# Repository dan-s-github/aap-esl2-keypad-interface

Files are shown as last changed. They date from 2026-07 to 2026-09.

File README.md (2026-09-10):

# AAP ESL-2 Keypad Interface

ESPHome firmware and a custom PCB to talk to the keypad bus of an [Arrowhead Alarm Products](https://www.aap.co.nz) EliteControl **ESL-2** panel, so it can be integrated into Home Assistant through the [`crow_alarm_panel`](https://github.com/dan-s-github/esphome-components) external component. It builds on my `crow_alarm_panel` implementation, which handles the AAP keypad bus protocol.

| PCB | PCB with Atom Lite | Side View |
| --- | --- | --- |
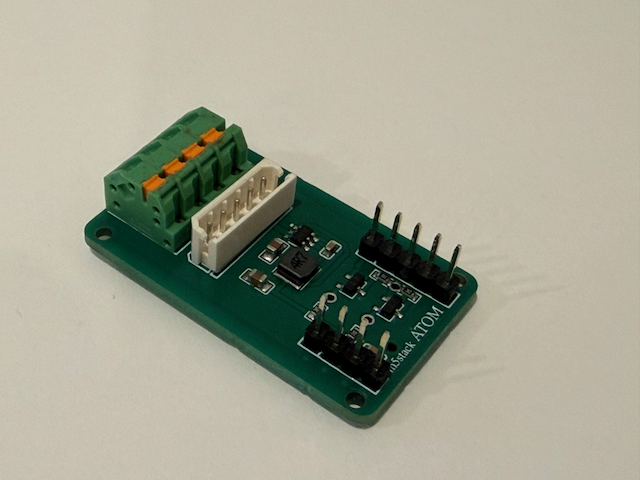
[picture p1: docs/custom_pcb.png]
Custom PCB
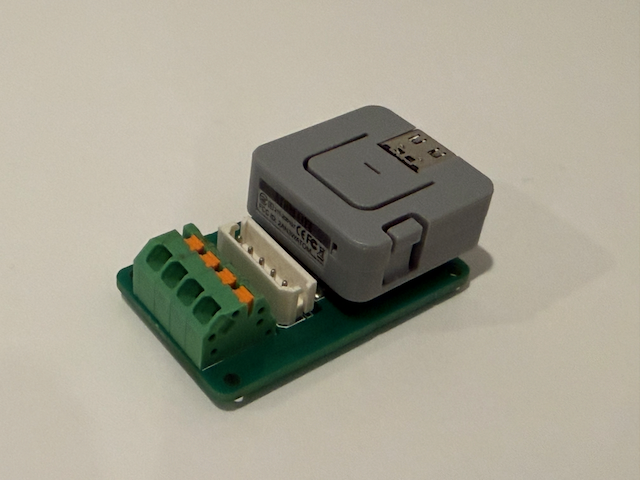
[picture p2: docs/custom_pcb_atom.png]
Custom PCB with Atom Lite
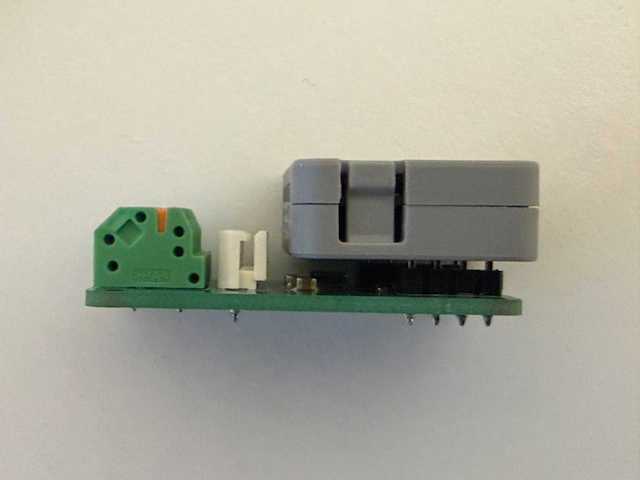
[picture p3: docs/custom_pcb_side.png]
Custom PCB on the side
|  |  |  |

The ESL-2 keypad bus is a shared clock/data bus that regular AAP keypads talk to. This project adds an [M5Stack Atom Lite](https://docs.m5stack.com/en/core/Atom%20Lite) or [M5Stack AtomS3 Lite](https://docs.m5stack.com/en/core/AtomS3%20Lite) to the bus as an extra keypad, so it can read zone/arm state and issue arm/disarm/output commands over Wi-Fi, without touching the panel's existing keypads.

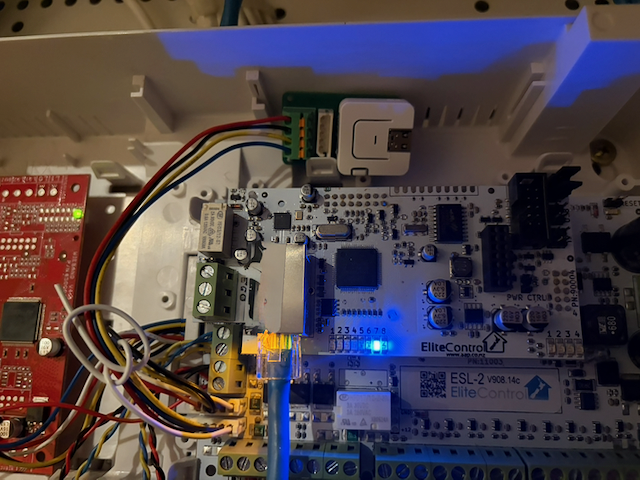
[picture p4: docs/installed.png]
Installed
  

## How it works

The panel supplies +12V to power the bus, but the clock/data lines themselves run at 5V, while the AtomS3 Lite module's GPIOs are 3.3V. The custom PCB sits between the two:

- An [`AP63205WU-7`](https://www.diodes.com/part/view/AP63205) buck converter steps the bus's +12V supply down to +5V, used as the CLK/DATA logic-high reference and to power the module.
- Two `BSS138` MOSFETs form bidirectional logic-level shifters for the CLK and DATA lines, translating between the bus side (5V) and the module side (3.3V).
- The PCB's pin header/Grove-compatible footprint matches the Atom Lite, so it plugs straight onto the PCB with no jumper wires — only the bus connection (panel to PCB) needs wiring, covered in [Connection diagram](#connection-diagram).

The header footprint matches the M5Stack ATOM family in general, so the original [M5Stack Atom Lite](https://docs.m5stack.com/en/core/ATOM%20Lite) (ESP32) works as a drop-in alternative to the AtomS3 Lite — it needs the plain `esp32` variant instead of `esp32s3`, plus different `clock_pin`/`data_pin` values in the YAML, since the Atom Lite exposes a different set of GPIOs than the AtomS3 Lite.

There is no dedicated address pin/DIP switch — the keypad address used on the bus is set entirely in the ESPHome YAML (see [Configuration](#configuration) below).

## Custom PCB

All manufacturing files (schematic, gerbers, BOM, pick-and-place, and the EasyEDA source project) are in [`docs/pcb`](docs/pcb/), ready to order from a board house such as [JLCPCB](https://jlcpcb.com/).

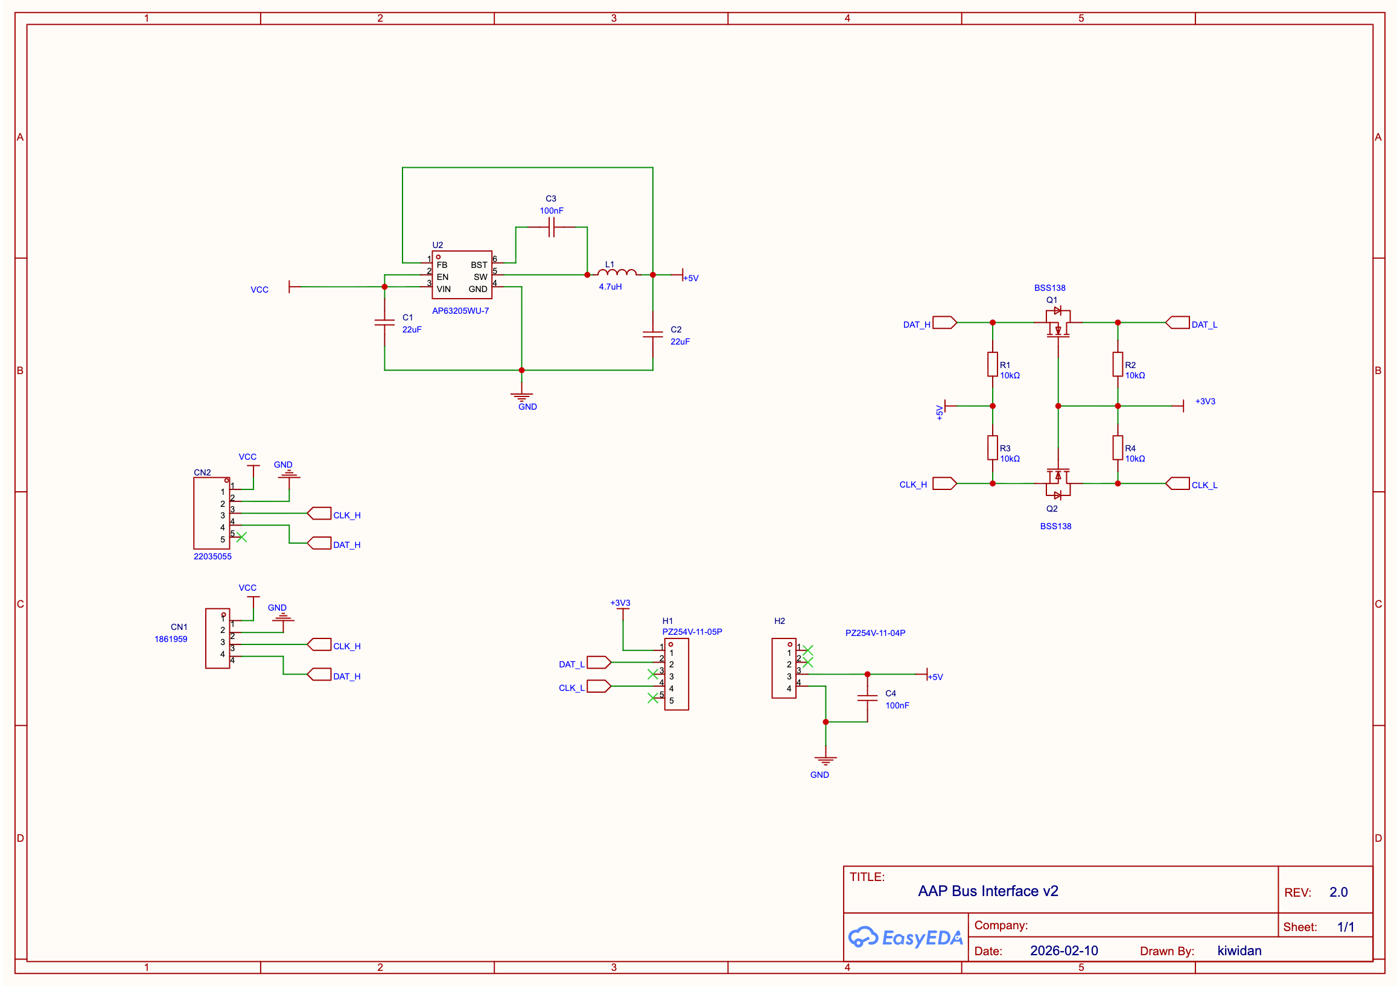
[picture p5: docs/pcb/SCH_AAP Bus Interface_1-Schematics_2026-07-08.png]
Schematics
  

- [Schematics PDF](docs/pcb/SCH_AAP%20Bus%20Interface_2026-07-08.pdf)
- [EasyEDA project](docs/pcb/ProPrj_AAP%20Bus%20Interface%20v2_2026-07-08.epro2) / [EasyEDA doc](docs/pcb/ProDoc_AAP%20Bus%20Interface_2026-07-08.epro2)

Files required to order boards from JLCPCB:

- [Gerber files](docs/pcb/Gerber_PCB_AAP_Bus_Interface_2026-07-08.zip)
- [Bill of Materials](docs/pcb/BOM_AAP%20Bus%20Interface_PCB_AAP%20Bus%20Interface_2026-07-08.csv)
- [Pick and Place](docs/pcb/PickAndPlace_PCB_AAP%20Bus%20Interface_2026_07_08.csv)

### Board layout

The top side mounts the AtomS3 Lite and carries the buck converter and level shifters. The bottom side breaks out the bus connection, silkscreened with the wire colors used on the ESL-2 keypad harness:

| Silkscreen | Signal | Wire color |
|---|---|---|
| +12V | Bus power | Red |
| GND | Ground | Black |
| CLK | Clock | Yellow |
| DAT | Data | Blue |

| Top | Bottom |
| --- | --- |
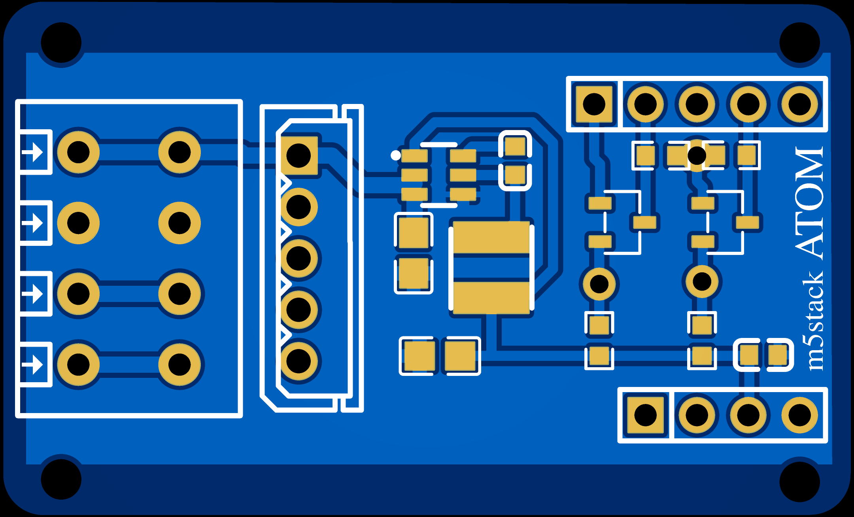
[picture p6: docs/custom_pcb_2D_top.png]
2D Top
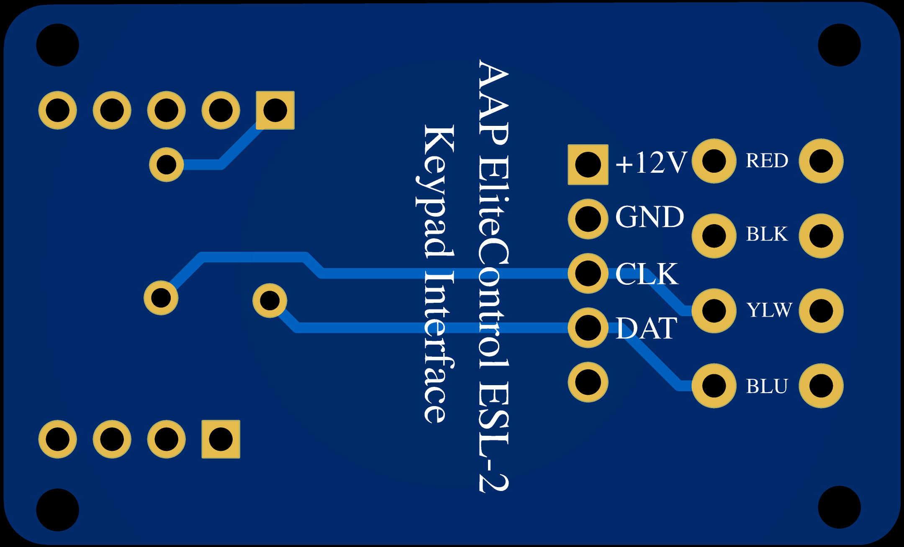
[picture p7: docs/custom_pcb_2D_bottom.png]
2D Bottom
|  |  |
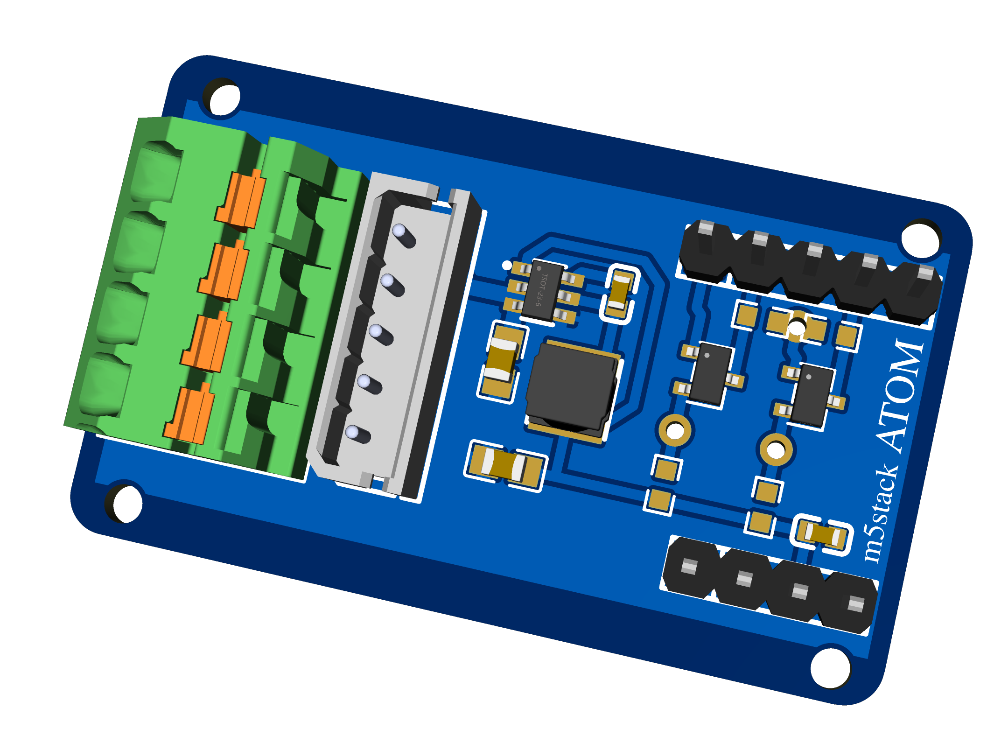
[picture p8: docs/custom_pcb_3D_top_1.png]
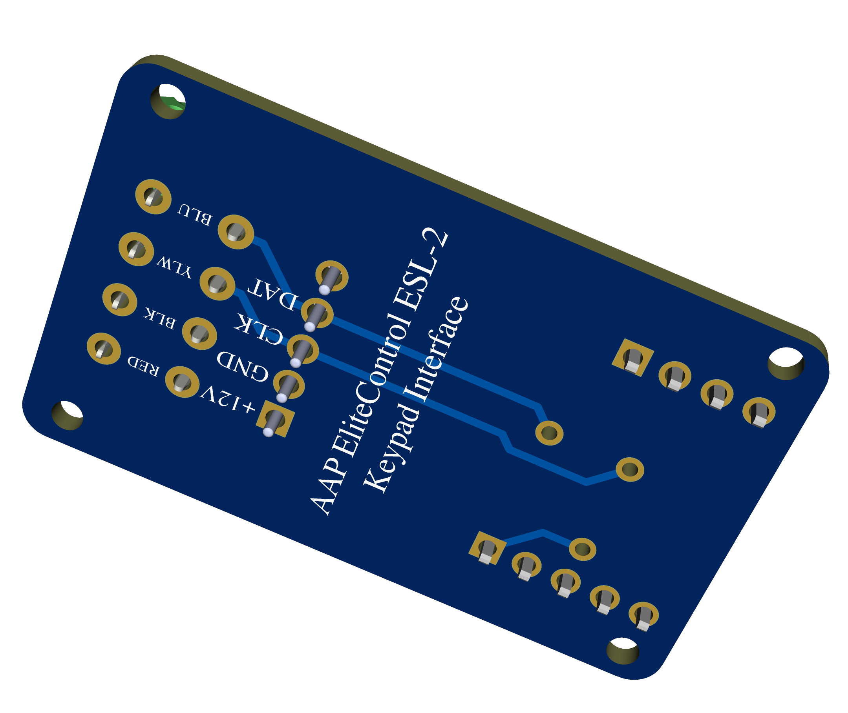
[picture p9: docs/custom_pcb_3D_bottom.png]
3D Bottom
|  |  |
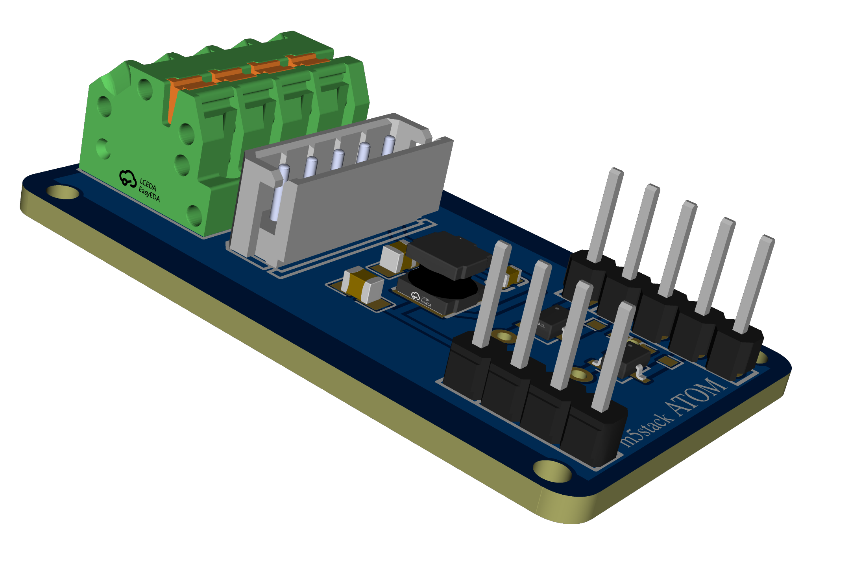
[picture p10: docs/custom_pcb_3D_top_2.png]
|  | |

Two options are provided for connecting to the bus:

- `CN1` — a 4-pin screw terminal (Phoenix Contact 1861959), for connecting bare wires directly.
- `CN2` — a 5-pin pluggable connector (Molex 22035055), for a crimped/pre-made harness — compatible with AAP's Keypad Bus Connection Cables. [ARR14](https://www.aap.co.nz/shop/Alarm+Systems/Keypads/ARR14.html), [ARR15](https://www.aap.co.nz/shop/Alarm+Systems/Keypads/ARR15.html), or the cheaper [AliExpress 5-pin, double-head cable](https://www.aliexpress.com/item/1005005383036734.html)

### Connection diagram

```txt
+--------------------+                +-----------------+
|    ESL-2 Panel     |                |    Custom PCB   |
|                    |                |                 |
| +12V (red)    o---------------------o +12V            |
| GND  (black)  o---------------------o GND             |
| CLK  (yellow) o---------------------o CLK             |
| DAT  (blue)   o---------------------o DAT             |
+--------------------+                +-----------------+
```

## 3D-Printable Case

An open-top OpenSCAD enclosure for the custom PCB lives in [`docs/case`](docs/case/):

| Case | With PCB fitted (reference) |
| --- | --- |
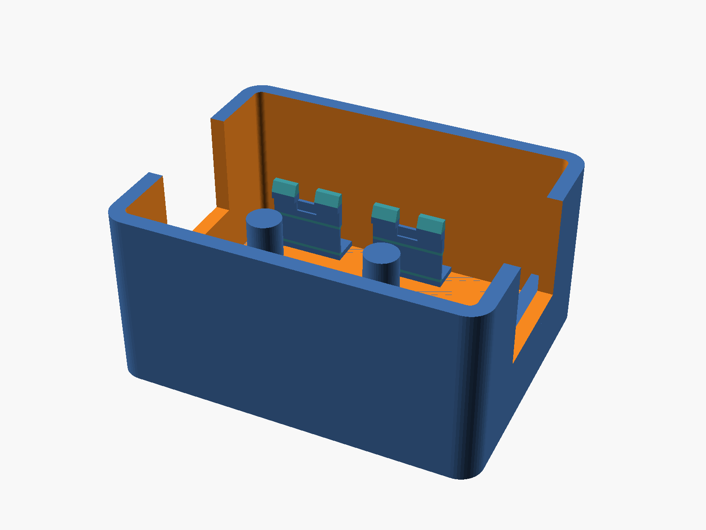
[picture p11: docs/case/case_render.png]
Case render
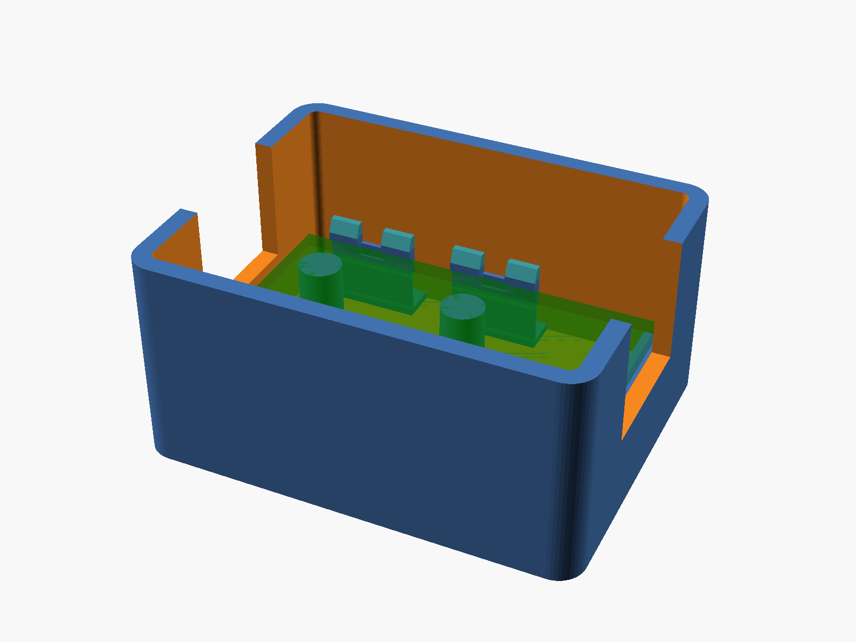
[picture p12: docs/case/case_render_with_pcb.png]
Case render with PCB
|  |  |

- [Latest STL (v5)](docs/case/AAP_Bus_Case_v5.stl) — view in GitHub's 3D preview, or grab the [zipped download](docs/case/AAP_Bus_Case_v5.stl.zip?raw=true) — ready to slice and print.
- [OpenSCAD source](https://github.com/dan-s-github/scad-pcb-enclosures/tree/main/cases/aap-bus-case) — parametric design, part of the [`scad-pcb-enclosures`](https://github.com/dan-s-github/scad-pcb-enclosures) multi-case repo.

The board has no mounting holes, so it's held by 4 press-fit support posts plus 4 snap-fit edge clips instead of screws. **Print the case in PETG or ABS, not PLA** — the edge clips flex on insertion and PLA is too brittle for the strain involved (one already cracked in PLA during testing). This design is still a work in progress: the clips have only been test-printed once, and CN2 (the pluggable bus connector) doesn't yet have wall access if it turns out to need it — see the repo's `docs/TODO.md` for open items.

## Configuration

Two example YAML configs are provided, both using the same PCB and wiring. Copy the one you need (dropping `.example`) and fill in your own zone/keypad names — the copy is gitignored so your real panel layout doesn't end up in the repo:

- [`aap_esl_keypad_interface.example.yaml`](aap_esl_keypad_interface.example.yaml) → `aap_esl_keypad_interface.yaml` — registers as an active keypad on the bus (`address: 5`) and exposes arm/disarm/stay, zone sensors, and switch outputs to Home Assistant.
- [`aap_esl_keypad_monitor.example.yaml`](aap_esl_keypad_monitor.example.yaml) → `aap_esl_keypad_monitor.yaml` — passive/listen-only variant (no `address` claimed on the bus), useful for monitoring bus traffic without presenting as a keypad.

Both use `clock_pin: GPIO7`, `data_pin: GPIO5` for the AtomS3 Lite (`GPIO23`/`GPIO22` instead if using an original Atom Lite, along with `esp32` instead of `esp32s3`) with the [`crow_alarm_panel`](https://github.com/dan-s-github/esphome-components) external component. For everything else — `keypads`, `zones`, passive monitor mode, outputs, bypass switches, the full option reference — see [the component's own README](https://github.com/dan-s-github/esphome-components/blob/main/components/crow_alarm_panel/README.md), which documents the schema in more detail than duplicated here.

If you notice odd log lines or occasional retry/timing behavior after setting this up, check the component's [known quirks page](https://github.com/dan-s-github/esphome-components/blob/main/components/crow_alarm_panel/docs/known_quirks.md) first — it covers benign bus/panel quirks (retransmission noise, watchdog re-announces, `CURRENT_TIME` glitches, etc.) that are already understood and don't indicate a problem with this integration.

Create a `secrets.yaml` (gitignored) alongside your copy with:

```yaml
wifi_ssid: "..."
wifi_password: "..."
fallback_hotspot_password: "..."
alarm_code: 1234
api_encryption_key: "..."
```

### Flash

Two ways to get this onto the device:

**Local CLI** — this project uses [`uv`](https://docs.astral.sh/uv/) to manage the ESPHome dependency (see [`pyproject.toml`](pyproject.toml)). [Install `uv`](https://docs.astral.sh/uv/getting-started/installation/) if you don't have it, then:

```sh
uv sync
uv run esphome config aap_esl_keypad_interface.yaml  # to validate configuration
uv run esphome run aap_esl_keypad_interface.yaml
```

**ESPHome Builder (Home Assistant add-on)** — no local ESPHome install needed:

1. In Home Assistant, open the ESPHome dashboard and `+ NEW DEVICE` to create a device and flash the stub firmware over USB (this sets up `wifi`, `api`, and `ota` for you, with the encryption key stored by the add-on).
2. Once the device shows up and adopts, `EDIT` it and replace the generated YAML's `esp32`, `logger`, `external_components`, and `crow_alarm_panel`/`text_sensor`/`alarm_control_panel`/`button`/`switch` blocks with the equivalent sections from [`aap_esl_keypad_interface.example.yaml`](aap_esl_keypad_interface.example.yaml), filled in with your own zones/keypads.
3. Leave the wizard-generated `wifi`/`api`/`ota` sections as-is — no need to bring in `secrets.yaml` since the add-on manages Wi-Fi credentials and the encryption key itself.
4. `INSTALL` to push the update over-the-air.

## Credits

[`crow_alarm_panel`](https://github.com/dan-s-github/esphome-components) was built on the work done by [jallier](https://github.com/jallier/esphome-components/tree/main/components) and [jesserockz](https://github.com/jesserockz/esphome-components/tree/main/components/crow_alarm_panel)

[custom_pcb]: docs/custom_pcb.png
[custom_pcb_atom]: docs/custom_pcb_atom.png
[custom_pcb_side]: docs/custom_pcb_side.png

[custom_pcb_2D_top]: docs/custom_pcb_2D_top.png
[custom_pcb_2D_bottom]: docs/custom_pcb_2D_bottom.png

[custom_pcb_3D_top_1]: docs/custom_pcb_3D_top_1.png
[custom_pcb_3D_top_2]: docs/custom_pcb_3D_top_2.png
[custom_pcb_3D_bottom]: docs/custom_pcb_3D_bottom.png

[installed]: docs/installed.png

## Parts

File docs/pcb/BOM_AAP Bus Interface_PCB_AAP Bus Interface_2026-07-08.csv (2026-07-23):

No. | Quantity | Comment | Designator | Footprint | Value | Manufacturer Part | Manufacturer | Supplier Part | Supplier
1 | 2 | 22uF | C1,C2 | C0805 | 22uF | CL21A226MAQNNNE | SAMSUNG(三星) | C45783 | LCSC
2 | 2 | 100nF | C3,C4 | C0603 | 100nF | CC0603KRX7R9BB104 | YAGEO(国巨) | C14663 | LCSC
3 | 1 | 1861959 | CN1 | CONN-TH_1861959 |  | 1861959 | Phoenix Contact(菲尼克斯) | C6656102 | LCSC
4 | 1 | 22035055 | CN2 | CONN-TH_22035055 |  | 22035055 | MOLEX | C293436 | LCSC
5 | 1 | PZ254V-11-05P | H1 | HDR-TH_5P-P2.54-V-M |  | PZ254V-11-05P | XFCN(兴飞) | C492404 | LCSC
6 | 1 | PZ254V-11-04P | H2 | HDR-TH_4P-P2.54-V-M |  | PZ254V-11-04P | XFCN(兴飞) | C2691448 | LCSC
7 | 1 | 4.7uH | L1 | IND-SMD_L4.0-W4.0_ZENR4030T | 4.7uH | ZENR4018T4R7M-4.7uH | ZE(增益) | C42428008 | LCSC
8 | 2 | BSS138 | Q1,Q2 | SOT-23-3_L3.0-W1.7-P0.95-LS2.9-BR |  | BSS138 | luJing(鲁晶) | C53058666 | LCSC
9 | 4 | 10kΩ | R1,R2,R3,R4 | R0603 |  | 0603WAF1002T5E | UNI-ROYAL(厚声) | C25804 | LCSC
10 | 1 | AP63205WU-7 | U2 | TSOT-23-6_L2.9-W1.6-P0.95-LS2.8-BL |  | AP63205WU-7 | DIODES(美台) | C2071056 | LCSC

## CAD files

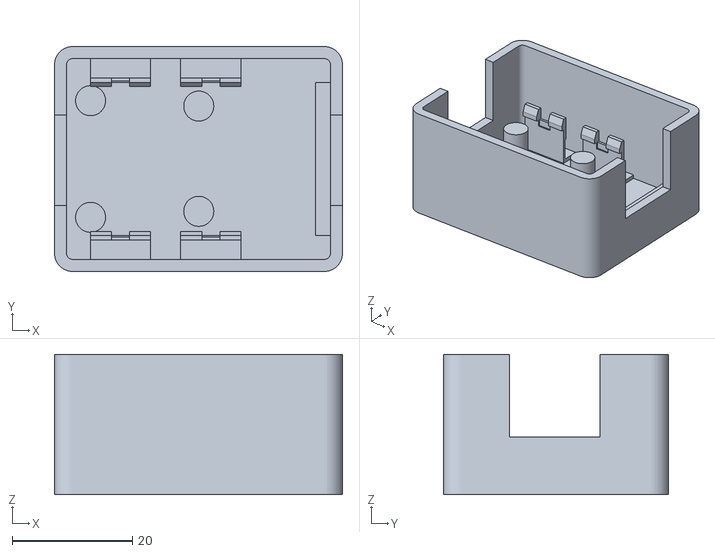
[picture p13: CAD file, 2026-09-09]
docs/case/AAP_Bus_Case_v5.stl
47.9 x 37.4 x 23.3

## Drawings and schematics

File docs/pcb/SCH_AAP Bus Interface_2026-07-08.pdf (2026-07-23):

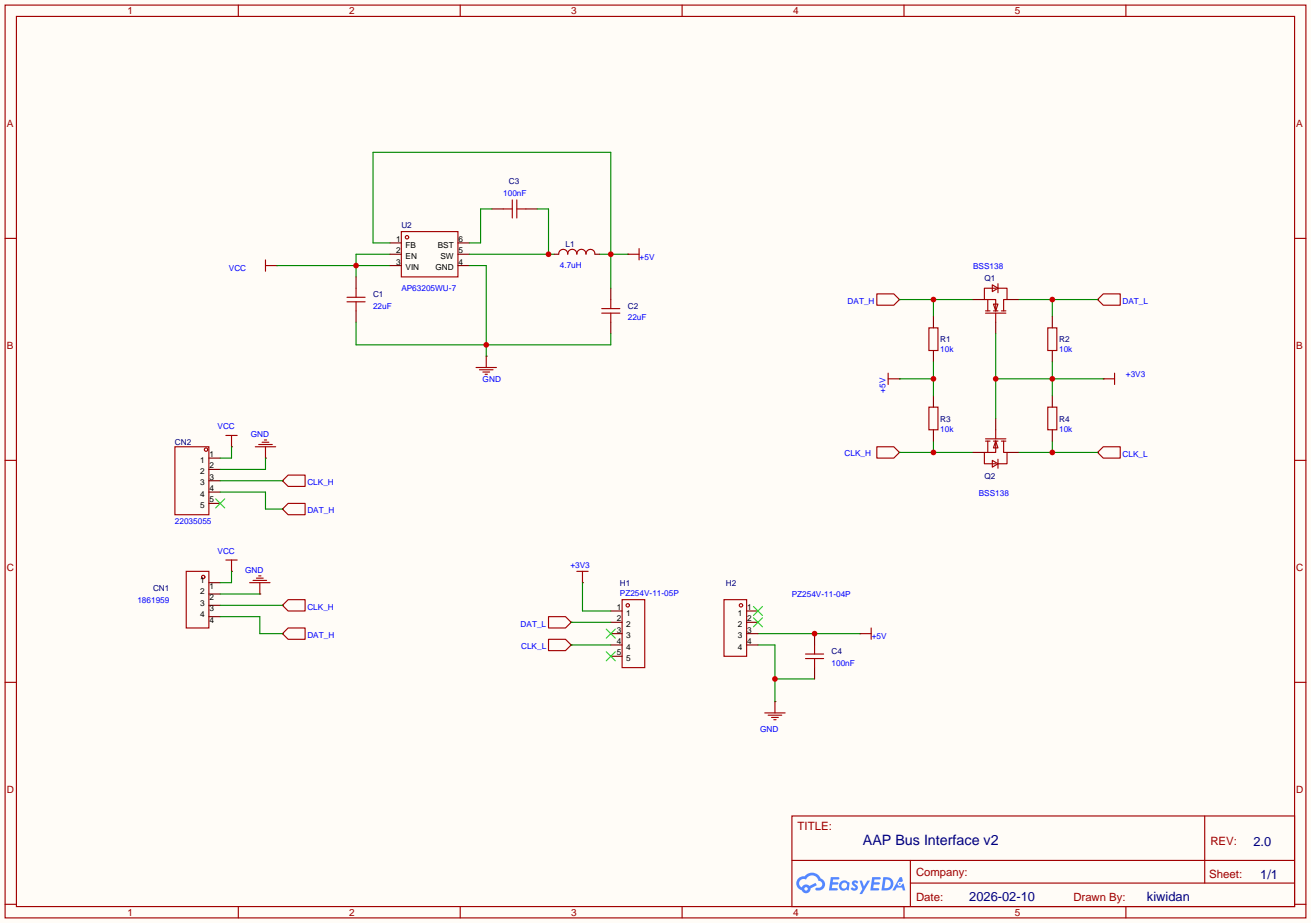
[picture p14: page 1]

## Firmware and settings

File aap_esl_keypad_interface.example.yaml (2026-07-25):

# Example configuration for the AAP ESL-2 Keypad Interface.
#
# Copy this file to `aap_esl_keypad_interface.yaml`, fill in your own zone
# and keypad names, and create a `secrets.yaml` alongside it (see README.md
# for the required keys). The copy is gitignored so your real layout stays
# local.

substitutions:
  name: "esphome-aap-alarm-interface"
  friendly_name: ESPHome AAP Alarm Interface
  comment: "Control your Arrowhead Alarm system using ESPHome."

esphome:
  name: ${name}
  friendly_name: ${friendly_name}
  comment: ${comment}
  name_add_mac_suffix: false

esp32:
  # AtomS3 Lite. If using an original Atom Lite instead, use `variant: esp32`
  # and clock_pin: GPIO23 / data_pin: GPIO22 below.
  variant: esp32s3
  framework:
    type: esp-idf

logger:
  level: DEBUG
  initial_level: INFO
  # Leave crow_alarm_panel unset here; the `select` below lets you switch
  # it to DEBUG at runtime instead of reflashing.
  # logs:
  #   crow_alarm_panel: DEBUG

external_components:
  - components: [crow_alarm_panel]
    source: github://dan-s-github/esphome-components

# Runtime log level control, so you can flip to DEBUG from Home Assistant
# without reflashing.
select:
  platform: logger
  name: "Log level"

crow_alarm_panel:
  # AtomS3 Lite pins. On an original Atom Lite use GPIO23 / GPIO22.
  clock_pin: GPIO7
  data_pin: GPIO5
  # Bus address this device claims as a keypad. Must not collide with any
  # other keypad already on the bus (physical keypads, RS232, IP, etc).
  address: 5
  code: !secret alarm_code

  # Every keypad the panel knows about, physical or virtual. Only used so
  # this component can identify bus traffic - it does not need to match
  # the panel's own keypad naming.
  keypads:
    - name: "Keypad 1"
      address: 0
    - name: "ESPHome Keypad"
      address: 5
    - name: "IP Keypad"
      address: 7

  # One entry per zone configured on the panel. `device_class` and `icon`
  # are passed straight through to the Home Assistant binary_sensor.
  zones:
    - zone: 1
      name: "Zone 1"
      device_class: motion
      icon: mdi:motion-sensor
    - zone: 2
      name: "Zone 2"
      device_class: motion
      icon: mdi:motion-sensor
    - zone: 3
      name: "Zone 3"
      device_class: garage_door
    - zone: 4
      name: "Zone 4"
      device_class: motion
      icon: mdi:motion-sensor
    - zone: 5
      name: "Zone 5"
      device_class: motion
      icon: mdi:motion-sensor
    - zone: 6
      name: "Zone 6"
      device_class: motion
      icon: mdi:motion-sensor
    - zone: 7
      name: "Zone 7"
      device_class: motion
      icon: mdi:motion-sensor
    - zone: 8
      name: "Zone 8"
      device_class: smoke

text_sensor:
  - platform: crow_alarm_panel
    type: armed_state
    name: "Alarm Status"

alarm_control_panel:
  - platform: crow_alarm_panel
    name: "Crow Alarm"
    requires_code_to_arm: false

button:
  - platform: crow_alarm_panel
    type: arm_away
    name: "Arm Away"

  - platform: crow_alarm_panel
    type: arm_stay
    name: "Arm Stay"

  - platform: crow_alarm_panel
    type: disarm
    name: "Disarm"

  - platform: restart
    id: restart_button
    name: "Restart"
    entity_category: diagnostic

# One `output` entry per panel PGM output you want to expose as a switch.
switch:
  - platform: crow_alarm_panel
    type: output
    output: 3
    name: "Output 3"
  - platform: crow_alarm_panel
    type: output
    output: 4
    name: "Output 4"

  # Runtime toggle for raw frame logging - noisy, so it's off by default
  # and left as a switch rather than a static logs: entry. Setting the
  # logger above to VERBOSE (via the `select`) enables the same raw frame
  # output, so this switch is only useful for isolating raw frames without
  # the rest of VERBOSE's noise.
  - platform: crow_alarm_panel
    type: log_raw_frames
    name: "Raw Frame Logging"

api:
  encryption:
    key: !secret api_encryption_key

ota:
  platform: esphome

improv_serial:

wifi:
  ssid: !secret wifi_ssid
  password: !secret wifi_password

  ap:
    ssid: "esphome-aap-keypad-fallback"
    password: !secret fallback_hotspot_password

captive_portal:

esp32_improv:
  authorizer: none

web_server:

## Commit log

2026-07-23 Initial commit: AAP ESL2 keypad interface for ESPHome
    Adds example ESPHome configs, custom PCB documentation/gerbers, and project setup files.
    [BOM_AAP Bus Interface_PCB_AAP Bus Interface_2026-07-08.csv, PickAndPlace_PCB_AAP Bus Interface_2026_07_08.csv]
2026-07-25 Add runtime log controls to example configs
    Replace the static crow_alarm_panel: DEBUG logger override with a
    logger `select` (runtime log level) and a crow_alarm_panel
    `log_raw_frames` switch, so debug/raw-frame logging can be toggled
    from Home Assistant instead of reflashing. Applied to both the
    interface and monitor examples for consistency. Also fixes the
    component README link in README.md to point at main instead of a
    stale refactor branch.
    [aap_esl_keypad_interface.example.yaml]
2026-09-09 Add 3D-printable case and known-quirks link to README
    Case design (STL + renders) lives under docs/case/, with the OpenSCAD
    source published separately in dan-s-github/scad-pcb-enclosures. Also
    point readers at the crow_alarm_panel component's known_quirks page so
    benign bus/log oddities aren't mistaken for integration bugs.
    Claude-Session: https://claude.ai/code/session_018VyCbmhhJ7irMrfJSWvtrH
    [AAP_Bus_Case_v5.stl]
2026-09-10 Fix case STL download link by adding a zipped copy
    The raw .stl link served with content-type text/plain and no
    attachment disposition, so GitHub rendered it inline instead of
    downloading. Zipping it sidesteps that; the raw .stl link is kept
    for GitHub's inline 3D preview.
    Claude-Session: https://claude.ai/code/session_01H69YEbamw9FDweg3MghMtz
2026-09-10 Add AliExpress cable source for CN2 keypad bus connector
    Cheaper alternative to AAP's own ARR14/ARR15 cables for the 5-pin
    pluggable harness.
    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
2026-09-15 Document AliExpress cable rollover pinout gotcha
    Some AliExpress CN2 cables ship wired rollover/mirrored instead of
    straight-through, which is needed here. Add cable_ok/cable_nok photos
    showing the correct vs incorrect pinout.
2026-10-14 Add panel fault sensors to example configs
    The crow_alarm_panel component gained trouble, trouble_latched,
    mains_fault and battery_fault binary sensors. Add them to both the
    interface and monitor examples (they decode the panel's status
    broadcast, so they work listen-only too) and mention them in the README.
